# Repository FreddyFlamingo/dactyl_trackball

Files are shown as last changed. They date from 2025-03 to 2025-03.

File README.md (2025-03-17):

# Dactyl Trackball

A customized split ergonomic keyboard based on mjohns Dactyl CC with integrated trackball functionality using the PWM3389 sensor and RP2040-based controllers.

Dactyl trackball

## Overview

This project modifies the original Dactyl CC design to integrate a 34mm trackball, allowing for cursor control without moving your hands from the keyboard. The design uses Pi Pico microcontrollers and the PWM3389 sensor for accurate trackball motion tracking.

### Features

* Split ergonomic design based on Dactyl CC
* 34mm trackball for cursor control
* RP2040-based controllers (Pi Pico)
* PWM3389 optical sensor for tracking
* QMK firmware with custom keymaps and trackball functionality
* Home row mods
* Multiple layers for different use cases (base, mod, mouse, calculator, code, etc.)

```
+--------+--------+--------+--------+--------+--------+                          +--------+--------+--------+--------+--------+--------+
|  ESC   |   1    |   2    |   3    |   4    |   5    |                          |   6    |   7    |   8    |   9    |   0    |  MINS  |
+--------+--------+--------+--------+--------+--------+                          +--------+--------+--------+--------+--------+--------+
|  TAB   |   Q    |   W    |   E    |   R    |   T    |                          |   Y    |   U    |   I    |   O    |   P    |  LBRC  |
+--------+--------+--------+--------+--------+--------+                          +--------+--------+--------+--------+--------+--------+
|  CAPS  |   A    |   S    |   D    |   F    |   G    |                          |   H    |   J    |   K    |   L    |  SCLN  |  QUOT  |
+--------+--------+--------+--------+--------+--------+                          +--------+--------+--------+--------+--------+--------+
|  LSFT  |   Z    |   X    |   C    |   V    |   B    |                          |   N    |   M    |  COMM  |  DOT   |  SLSH  |  RSFT  |
+--------+--------+--------+--------+--------+--------+                          +--------+--------+--------+--------+--------+--------+
         |  EQL   | NUBSS  |TO(CALC)|TO(PROG)|                                            |TO(NORM)|TO(CODE)|  NUHS  |  RBRC  |
         +--------+--------+--------+--------+                                            +--------+--------+--------+--------+

                                             +--------+--------+        +--------+--------+
                                             |  LCTL  |  LALT  |        |  RALT  |  RCTL  |
                                    +--------+--------+--------+        +--------+--------+--------+
                                    |        |        |  HOME  |        |  PGUP  |        |        |
                                    |  BSPC  |  DEL   +--------+        +--------+  ENT   |  SPC   |
                                    |        |        |  END   |        |  PGDN  |        |        |
                                    +--------+--------+--------+        +--------+--------+--------+
```

## Hardware Requirements

### Components

* 2× Raspberry Pi Pico microcontrollers
* PWM3389 trackball sensor (available on Tindie)
* 34mm trackball
* 3× roller bearings (3×6×2.5mm)
* 3× M3×6mm pins/dowels for roller bearings
* 2× 2.5/3.5mm TRRS jacks (PJ-320A recommended)
* TRRS cable for split communication
* 2× M2.5 screws and thread inserts for the motion sensor
* Diodes (1N4148)
* 26 AWG wire
* and more...

## Wiring Guide

The keyboard uses a standard matrix wiring approach with diodes. The trackball sensor connects to the controller via SPI. See the top left corner of the first picture below.

Wire picture
Wires
More wires
Mcu

## Build Process

I used [ntarocco's guide](https://github.com/ntarocco/dactyl-cc) as a base for the build, along with this [build log](https://medium.com/@kincade/track-beast-build-log-a-trackball-dactyl-manuform-19eaa0880222) of a trackball-integrated Dactyl Manuform.

### Case Modifications

I modified mjohns' original [Dactyl_CC](https://github.com/mjohns/dactyl-cc) STL files to:

1. Add a trackball holder to accommodate the 34mm ball
2. Edit the MCU holder to fit the Pi Pico controllers

### Lessons Learned and Recommendations

If you're building this keyboard, consider these recommendations:

- **Add protection for the motion controller**: The current design has the PWM3389 sensor exposed. Consider designing a cover or case for it.

- **Test all connections thoroughly before assembly**: Due to the tight space constraints with the Pi Pico, it's very difficult to fix wiring issues after assembly. The controller is quite long, requiring 90-degree bends in the wiring at solder points to fit inside the case.

## Components and Sourcing

I sourced components from various places:

- Most general components from Amazon and AliExpress
- PWM3389 trackball sensor from Tindie
- 34mm trackball from a variety of sources (suitable billiard balls or trackball replacements work well)

### Credits

- [mjohns](https://github.com/mjohns) for the original Dactyl CC design
- [ntarocco](https://github.com/ntarocco) for the build guide
- Kincade for the trackball integration inspiration
- [QMK Firmware](https://github.com/qmk/qmk_firmware) team for the keyboard firmware

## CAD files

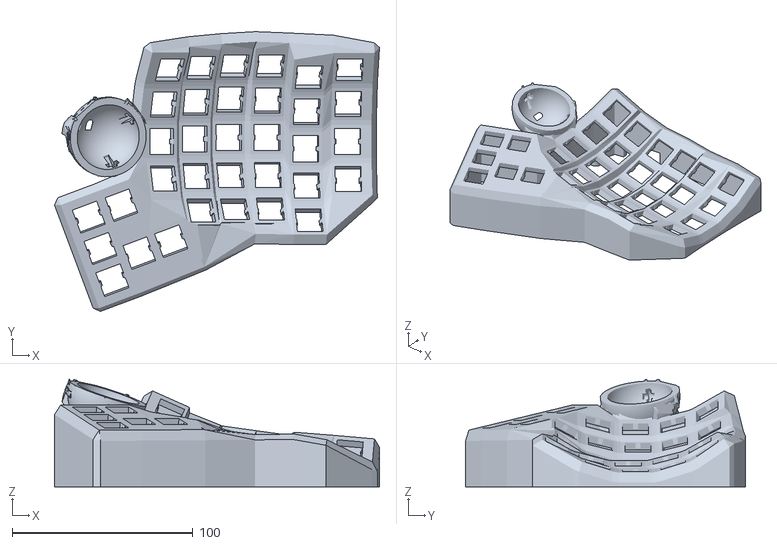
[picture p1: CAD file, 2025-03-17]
stl/rightv2.stl
179.7 x 154.7 x 59.4

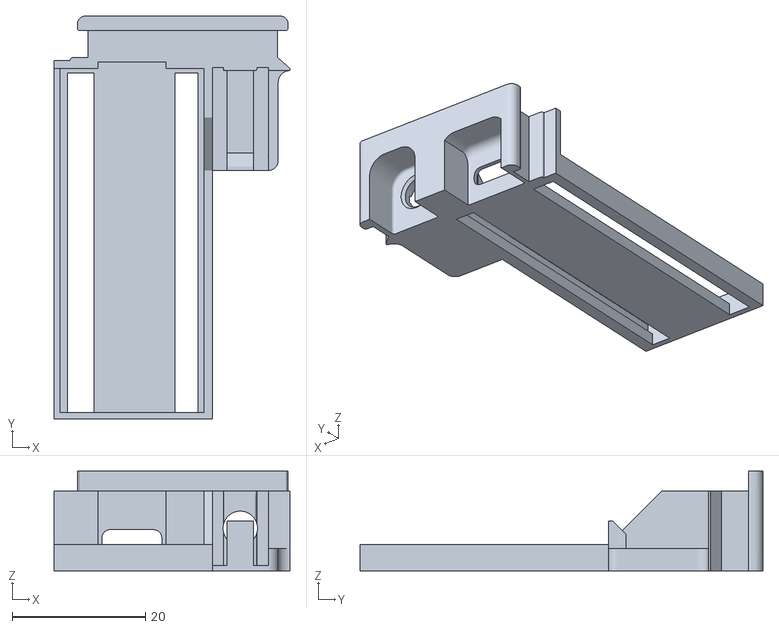
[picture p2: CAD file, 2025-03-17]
stl/holder_pi_pico _mirrored.stl
35.4 x 60.5 x 15.0

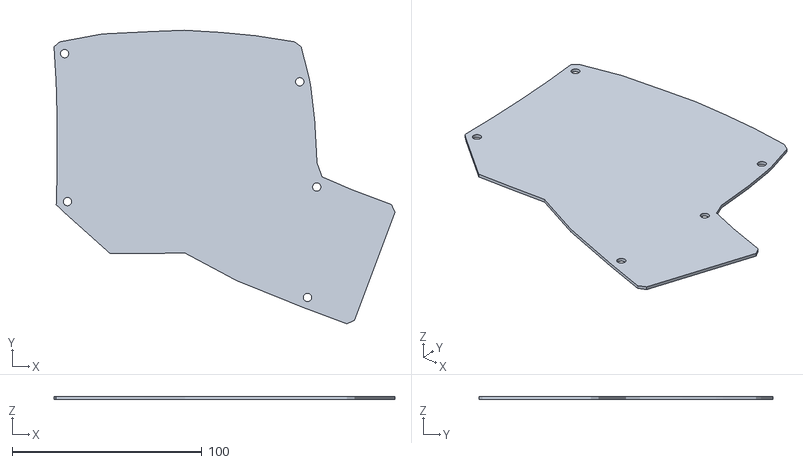
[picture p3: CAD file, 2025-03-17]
stl/bottom_left.stl
179.7 x 154.7 x 1.50

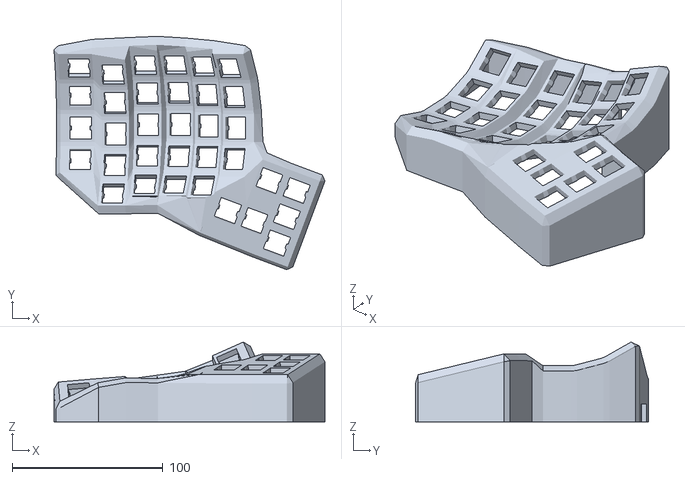
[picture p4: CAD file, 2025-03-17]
stl/left.stl
179.7 x 154.7 x 53.0

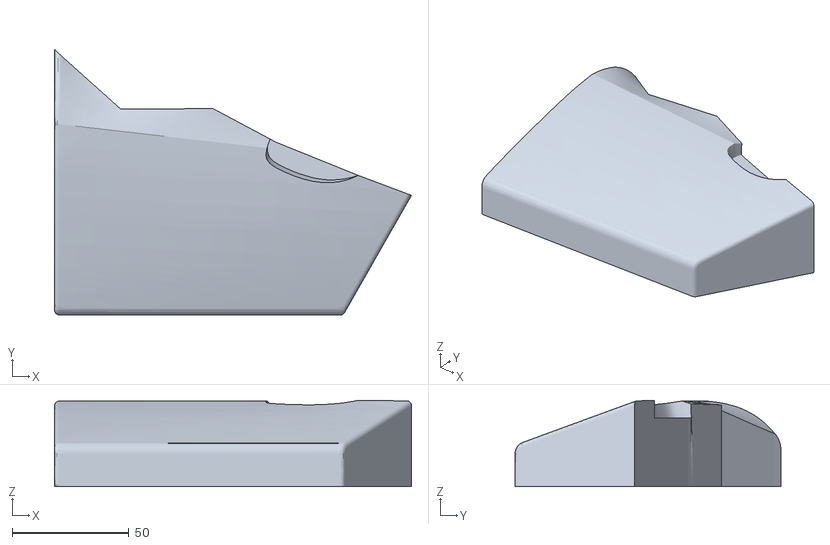
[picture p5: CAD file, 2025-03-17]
stl/test.stl
153.0 x 114.0 x 37.0

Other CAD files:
stl/bottom_right.stl
stl/holder_pi_pico.stl

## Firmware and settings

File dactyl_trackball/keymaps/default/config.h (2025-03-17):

// Copyright 2023 QMK
// SPDX-License-Identifier: GPL-2.0-or-later

#pragma once

/* Locking resynchronize hack */
#define LOCKING_RESYNC_ENABLE

/* Enables This makes it easier for fast typists to use dual-function keys */
#define PERMISSIVE_HOLD

/* layer config */
#define TAPPING_TOGGLE 2

#define MASTER_RIGHT
#define MATRIX_ROWS 12
#define MATRIX_COLS 6
#define SPLIT_MATRIX_ENABLE

/* Communication method used */ 
#define SERIAL_USART_FULL_DUPLEX 
#define SERIAL_USART_TX_PIN GP0
#define SERIAL_USART_RX_PIN GP1

/* SPI settings for PWM3389 FOR FUTURE */
#define SPI_DRIVER SPID0
#define SPI_SCK_PIN GP18
#define SPI_MOSI_PIN GP19
#define SPI_MISO_PIN GP16
#define PMW33XX_CS_PIN GP17

#define POINTING_DEVICE_INVERT_Y

#define PMW33XX_CPI 800 // default is 1600
#define PMW33XX_LIFTOFF_DISTANCE 0x01
